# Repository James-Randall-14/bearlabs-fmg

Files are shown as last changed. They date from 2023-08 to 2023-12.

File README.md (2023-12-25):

# BEAR LABS Wireless Force Myography Band

This repository contains all the CAD files, software, and information for the Wireless FMG band project. 
It's a work-in-progress, and the goal of this repository is to make it easier for people without prior experience on this project to continue working on it.

This README has three sections:

  - [Mechanical and Electrical Details](#mechanical-and-electrical-details)
    - [Parts](#parts)
    - [Housings](#housings)
  - [Software Details](#software-details)
  - [Issues and Future Improvements](#issues-and-future-improvements)

## Mechanical and Electrical Details

### Parts
* [Unexpected Maker TinyS3 ESP32 Microcontroller](https://esp32s3.com/tinys3.html).

It's got support for Bluetooth Low Energy, and 9 analog inputs, which is one more than we need.

* [Force Sening Resistors](https://buyinterlinkelectronics.com/products/fsr-400-short)

8 total, one per housing unit.

* Generic Boa Clip

We've got several in the lab, any one of them is fine.

* [200mAh LiPo Battery](https://a.co/d/5Q56SUB)

Having 3 of these on hand gives us the ability to run the FMG band indefinitely, because batteries can be easily swapped out.

### Housings

All housings are printed from PLA, and have a TPE pad between the PLA and subject's skin. 
Each housing has a rectangular channel, with two circular holes on either side. The rectangular channel is for passing wires through, and the circular holes are for the boa clip wires. This would ideally allow the distance between the housings to change as the band is tightened/loosened.

The TPE pad makes wearing the band more comfortable, and has a 100% infill cylinder to activate the FSR.
There are 8 total housings, and each one has an FSR, but some are larger so that they can carry extra hardware.

#### There are 3 types of housing:

The **main housing** contains the ESP32 Microcontroller, has an FSR cutout on the bottom, and it's super wide so that we can stick the boa lace on the top. There is only one of these housings.

The **battery housing** is also very large, so that we can fit the battery inside. It's also got an FSR cutout on the bottom. Currently, there is only one of these housings, but in the future it would be possible to replace generic housings with these guys to extend battery life.

The **generic housing** is much smaller, and is essentially just a home for a force sensor. At current spec, there are 6 of these, bringing the total number of housings to 8.

All housing CAD models can be found in the cad_files folder.

## Software Details

The software is comparatively much simpler. 

In the ble_server file there is some arduino code that runs on the microcontroller. It creates a Bluetooth Low Energy server which waits for a client connection, and then broadcasts data read from the analog inputs.

Every time a BLE Server sends data, there's a delay, because it has to wait for a confirmation from the client. 
So to minimize this delay, the microcontroller samples 64 times, and then sends that data as an array of length 512. If you want to understand this more thoroughly, [here is an excellent article](https://interrupt.memfault.com/blog/ble-throughput-primer).

The BLE client program creates a connection to the BLE server, and it's responsible for parsing the long array back into the samples from the FSRs. For now, it just records the data into a .csv file. Take a look at `example.csv` to see what that looks like.

If there are any questions, please email me at randallj24@student.jhs.net or text me at 801-347-6334.

---
Written by James Randall, Jesuit High School '24

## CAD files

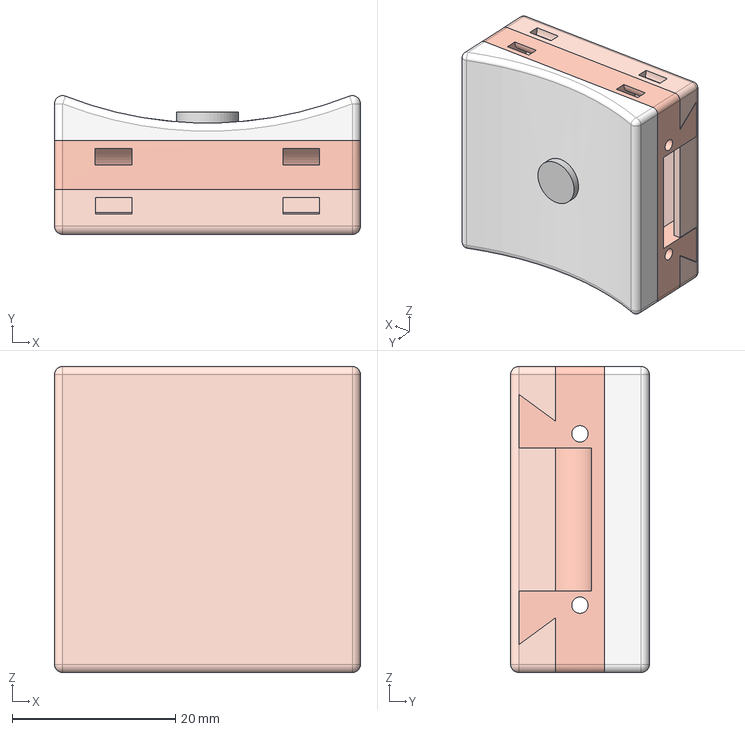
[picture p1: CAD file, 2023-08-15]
cad_files/Main Housing.step
37.5 x 17.0 x 37.5 mm

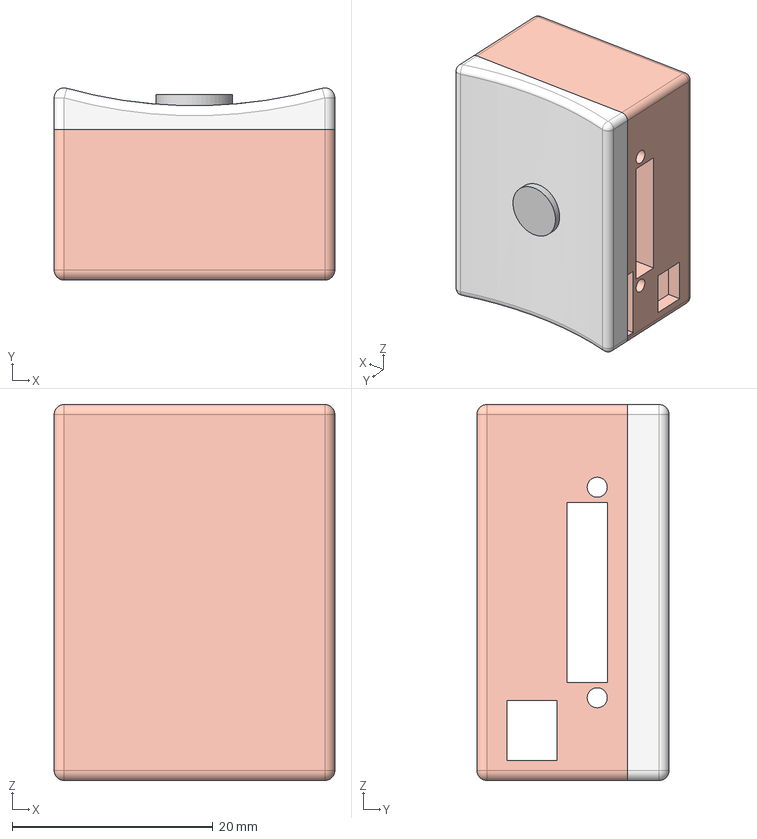
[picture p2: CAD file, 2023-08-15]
cad_files/Battery Housing.step
28.0 x 19.2 x 37.5 mm

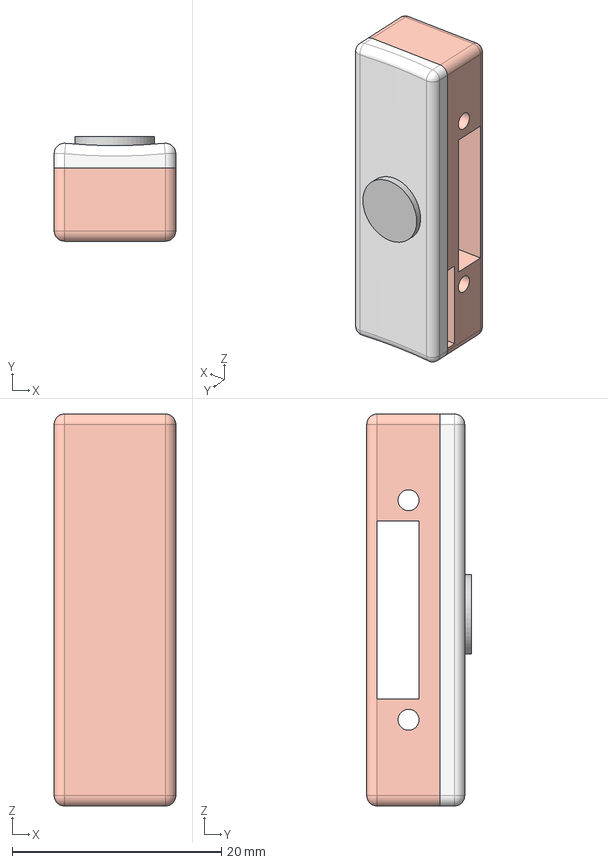
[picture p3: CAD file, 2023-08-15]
cad_files/Generic Housing.step
11.6 x 10.0 x 37.5 mm

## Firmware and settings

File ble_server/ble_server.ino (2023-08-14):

/*
    Video: https://www.youtube.com/watch?v=oCMOYS71NIU
    Based on Neil Kolban example for IDF: https://github.com/nkolban/esp32-snippets/blob/master/cpp_utils/tests/BLE%20Tests/SampleNotify.cpp
    Ported to Arduino ESP32 by Evandro Copercini
    updated by chegewara

   Create a BLE server that, once we receive a connection, will send periodic notifications.
   The service advertises itself as: 4fafc201-1fb5-459e-8fcc-c5c9c331914b
   And has a characteristic of: beb5483e-36e1-4688-b7f5-ea07361b26a8

   The design of creating the BLE server is:
   1. Create a BLE Server
   2. Create a BLE Service
   3. Create a BLE Characteristic on the Service
   4. Create a BLE Descriptor on the characteristic
   5. Start the service.
   6. Start advertising.

   A connect hander associated with the server starts a background task that performs notification
   every couple of seconds.
*/
#include <BLEDevice.h>
#include <BLEServer.h>
#include <BLE2902.h>
#include <iostream>

BLEServer* pServer = NULL;
BLECharacteristic* pCharacteristic = NULL;
bool deviceConnected = false;
bool oldDeviceConnected = false;
int x; // index variable. Not called index for redefinition reasons
uint16_t fsr_vals[64][8] = {0};


// See the following for generating UUIDs:
// https://www.uuidgenerator.net/

#define SERVICE_UUID        "e2653d64-d106-4a30-bca9-938b405b9735"
#define CHARACTERISTIC_UUID "4b974cb0-aa54-48fa-8bcc-e82e030362e2"

class MyServerCallbacks: public BLEServerCallbacks {
    void onConnect(BLEServer* pServer) {
      deviceConnected = true;
      BLEDevice::startAdvertising();
    };

    void onDisconnect(BLEServer* pServer) {
      deviceConnected = false;
    }
};

void measure_fsrs(int outer_index) {
  if (outer_index >= sizeof(fsr_vals)/sizeof(fsr_vals[0])) {
    throw std::invalid_argument("Tried to write to an FSR index that was out of bounds");
  }
  for(int i = 0; i < sizeof(fsr_vals[0])/sizeof(fsr_vals[0][0]); i++) {
    uint16_t val = analogRead(i + 1); // Analog input pins are pins 1-8
    fsr_vals[outer_index][i] = val;
  }
}

void setup() {
  Serial.begin(115200);
  analogReadResolution(12); // Tinys3 has a ADC resolution of 12 bits

  // Set pins into input mode
  for (int i = 0; i <= 8; i++) {
    pinMode(i, INPUT);
  }

  // Create the BLE Device
  BLEDevice::init("FMG_Band");

  // Create the BLE Server
  pServer = BLEDevice::createServer();
  pServer->setCallbacks(new MyServerCallbacks());

  // Create the BLE Service
  BLEService *pService = pServer->createService(SERVICE_UUID);

  // Create a BLE Characteristic
  pCharacteristic = pService->createCharacteristic(
                      CHARACTERISTIC_UUID,
                      BLECharacteristic::PROPERTY_READ   |
                      BLECharacteristic::PROPERTY_WRITE  |
                      BLECharacteristic::PROPERTY_NOTIFY |
                      BLECharacteristic::PROPERTY_INDICATE
                    );

  // https://www.bluetooth.com/specifications/gatt/viewer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
  // Create a BLE Descriptor
  pCharacteristic->addDescriptor(new BLE2902());

  // Start the service
  pService->start();

  // Start advertising
  Serial.println("Waiting on a client...");
  BLEAdvertising *pAdvertising = BLEDevice::getAdvertising();
  pAdvertising->addServiceUUID(SERVICE_UUID);
  pAdvertising->setScanResponse(false);
  pAdvertising->setMinPreferred(0x0);  // set value to 0x00 to not advertise this parameter
  BLEDevice::startAdvertising();
}

void loop() {
    // notify changed value
    if (deviceConnected) {

        measure_fsrs(x);

        x += 1;

        // Reset index so we don't oob
        if (x >= 64) {
            pCharacteristic->setValue((uint8_t*)&fsr_vals, 512);
            pCharacteristic->notify();
            Serial.println("Reached end of array");
            x = 0;
            //delay(2); // If msgs are sent too quickly, BLE can get congested.
        }
    }

    // disconnecting
    if (!deviceConnected && oldDeviceConnected) {
        Serial.println("Disconnected");
        delay(500); // give the bluetooth stack the chance to get things ready
        pServer->startAdvertising(); // restart advertising
        Serial.println("Restarting advertising");
        oldDeviceConnected = deviceConnected;
    }

    // connecting
    if (deviceConnected && !oldDeviceConnected) {
        Serial.println("Connecting to a new device");
        // do stuff here on connecting
        oldDeviceConnected = deviceConnected;
    }
}

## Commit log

2023-07-19 broken, workin on it
    [ble_server.ino]
2023-08-14 transmitting data. Approx 1850 samples / second
2023-08-15 added documentation and finalized for non-me usage
    [2023-08-15_19-49-50.csv, Battery Housing.step, Generic Housing.step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]
